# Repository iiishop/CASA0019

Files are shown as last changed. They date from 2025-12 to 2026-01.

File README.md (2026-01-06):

# Study Space Availability and Comfort Monitoring  
**CASA0019 – Sensor Data Visualisation**  
UCL MSc Connected Environments

---

## 1. Introduction & Rationalization

Bookable study spaces play a key role in shaping how students focus, interact, and collaborate. Their availability and atmosphere directly affect both individual productivity and group work.

At UCL, a web-based reservation system allows students to check availability in advance. While effective for scheduling, it represents space mainly through box-style time slots and simplified visuals, offering little insight into experiential qualities such as comfort or suitability for different modes of work. As a result, students often still need to visit spaces in person to assess their appropriateness, and operationally it remains difficult to perceive how spaces respond to changing occupancy and conditions over time.

Prior research shows that students’ study-space choices are shaped by a combination of environmental comfort and functional needs, including noise, privacy, and facilities (Beckers, van der Voordt, & Dewulf, 2016). Indoor environmental conditions have also been shown to significantly influence comfort, satisfaction, and performance, as demonstrated through integrated post-occupancy evaluation approaches combining monitored data with subjective and objective measures (Andargie & Azar, 2019).

This project does not replace the existing system, but reinterprets its data through visualisation. By combining physical data visualisation with a digital twin, it explores how availability and room dynamics can be perceived passively rather than actively queried. Through physical form and visual behaviour, the system frames visualisation as sense-making—supporting everyday student decisions while also providing facilities teams with higher-level insight into learning space performance over time.

<p align="center">
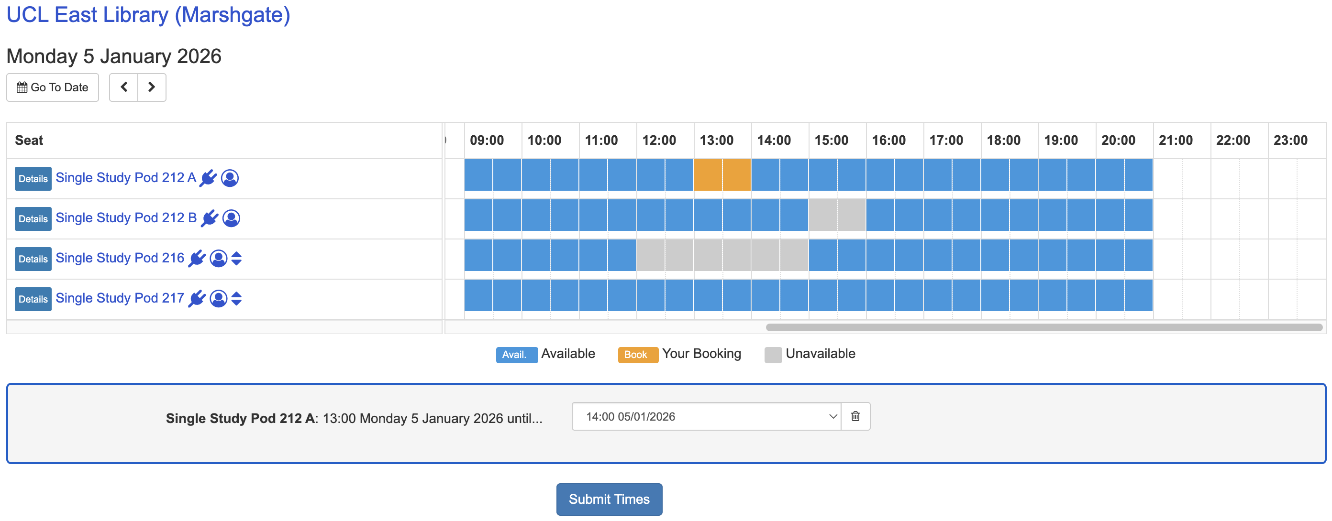
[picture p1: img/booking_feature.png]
Figure 1. Existing Bookable Study Space System
  
</p>

<p align="center"><em>Figure 1. Existing Bookable Study Space System</em></p>

---

## 2. From Data to Visual Language

The project translates key spatial conditions into a visual language that can be perceived intuitively. The system combines two types of data: availability information derived from the UCL Library Reservation booking API, and a set of simulated environmental and behavioural indicators designed to explore how the atmosphere of learning spaces might be communicated visually rather than numerically.

Availability is taken from the booking API and converted into a 30-minute free/booked timeline for each study space across the day (09:00–21:00), updated at regular intervals. This representation supports quick comparison of when a space is likely to be usable, without requiring users to read or interpret detailed schedules or time-slot tables.

To represent comfort and room dynamics, the project focuses on four indicators: occupancy percentage, noise, lighting, and temperature. In the current prototype, these values are synthetically generated within plausible ranges and treated as relative perceptual signals rather than precise measurements. The logic used to generate and update these indicators is implemented in a Python-based simulation module, which is publicly available as part of the project repository (see study_space_simulator.py).

<table align="center">
  <tr>
    <td align="center">
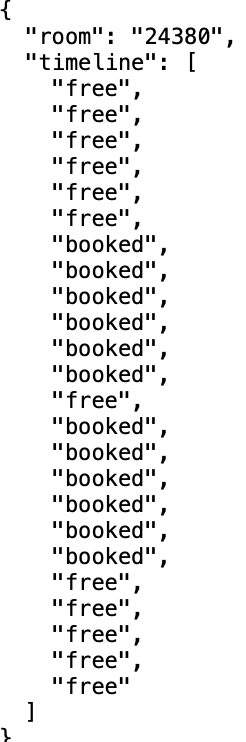
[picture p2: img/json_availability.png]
Figure 2. Sample JSON Output of Availability Data
      
    </td>
    <td align="center">
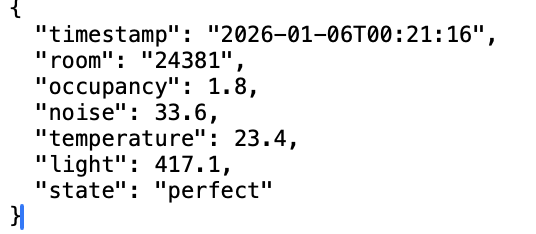
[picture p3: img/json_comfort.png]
Figure 3. Sample JSON Output of Comfort Data
      
    </td>
  </tr>
  <tr>
    <td align="center">
      <em>Figure 2. Sample JSON Output of Availability Data</em>
    </td>
    <td align="center">
      <em>Figure 3. Sample JSON Output of Comfort Data</em>
    </td>
  </tr>
</table>

---

## 3. Physical Data Visualization Device

The physical data visualisation device is conceived as a passive, ambient interface that communicates the state of study spaces at a glance. Rather than functioning as an interactive dashboard, the device supports quick, intuitive interpretation through form, colour, and movement, aligning with everyday study decisions that require rapid assessment rather than detailed analysis.

<p align="center">
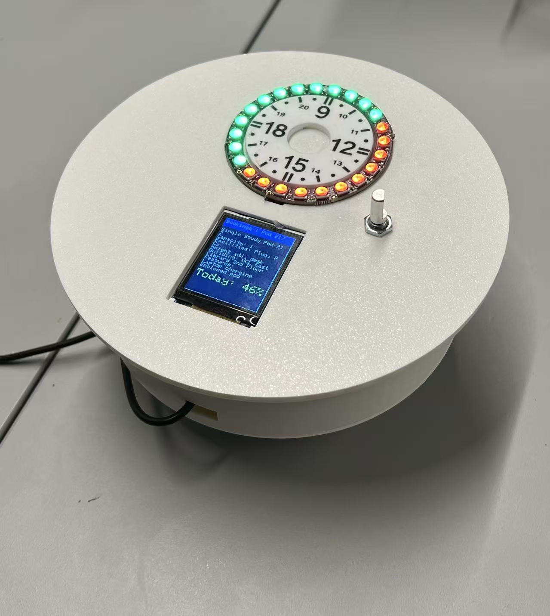
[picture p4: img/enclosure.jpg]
Figure 4. Final Physical Device Enclosure
  
</p>

<p align="center"><em>Figure 4. Final Physical Device Enclosure</em></p>

The device adopts a tabletop form factor with a circular geometry, inspired by the metaphor of a round conference table associated with collaborative learning. The enclosure was designed in Fusion 360 and fabricated through 3D printing, aligning the physical form with the system’s data logic and interaction model. One study space is presented at a time, with navigation handled via a rotary encoder for switching spaces and modes, supporting calm, sequential exploration.

A NeoPixel LED ring serves as the primary medium for temporal and quantitative representation. In Bookings mode, the ring maps the day from 09:00 to 21:00 using 24 LEDs to represent 30-minute intervals, with green indicating availability and red indicating bookings. A circular acrylic overlay, engraved to resemble a watch face, provides a familiar temporal reference for the abstract LED timeline.

In Condition mode, the ring transitions to an animated display of room dynamics, cycling through occupancy, noise, temperature, and lighting. Colour identifies the active attribute, while the number of illuminated LEDs encodes relative magnitude. Progressive filling and rotation communicate intensity and change over time through visual behaviour.

The TFT screen complements the LED ring by providing contextual information. In Bookings mode, it displays room details and overall booking levels, while in Condition mode it presents expressive icons rather than numerical values to reinforce perceptual understanding and reduce cognitive load.

Overall, the device is designed to be readable without instruction. By embedding data within physical form and visual behaviour, it translates abstract spatial information into an intuitive, ambient presence that supports everyday decision-making in learning environments.

<p align="center">
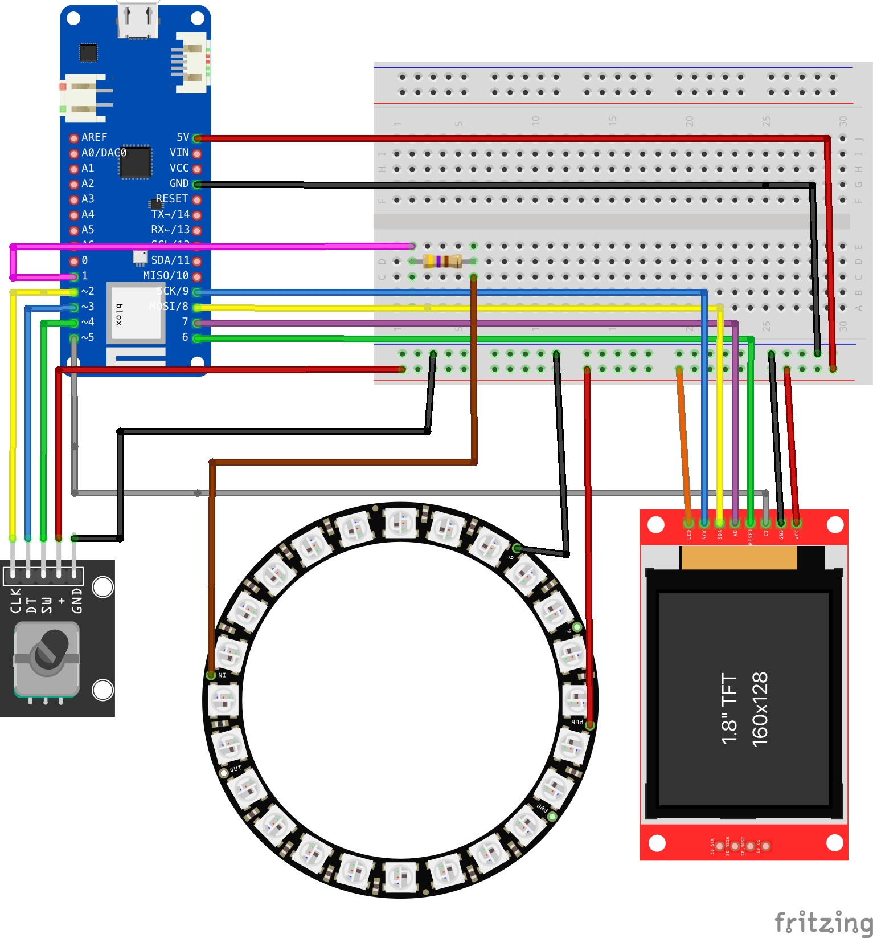
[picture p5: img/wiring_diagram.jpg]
Figure 5. Wiring Diagram
  
</p>

<p align="center"><em>Figure 5. Wiring Diagram</em></p>

---

## 4. Digital Visualization and Digital Twin

The digital twin extends the physical data visualisation device into a complementary digital medium that supports different forms of interpretation. While the physical device is designed for peripheral, glance-based awareness in real space, the digital twin enables closer inspection and comparison without altering the underlying data or system logic.

<p align="center">
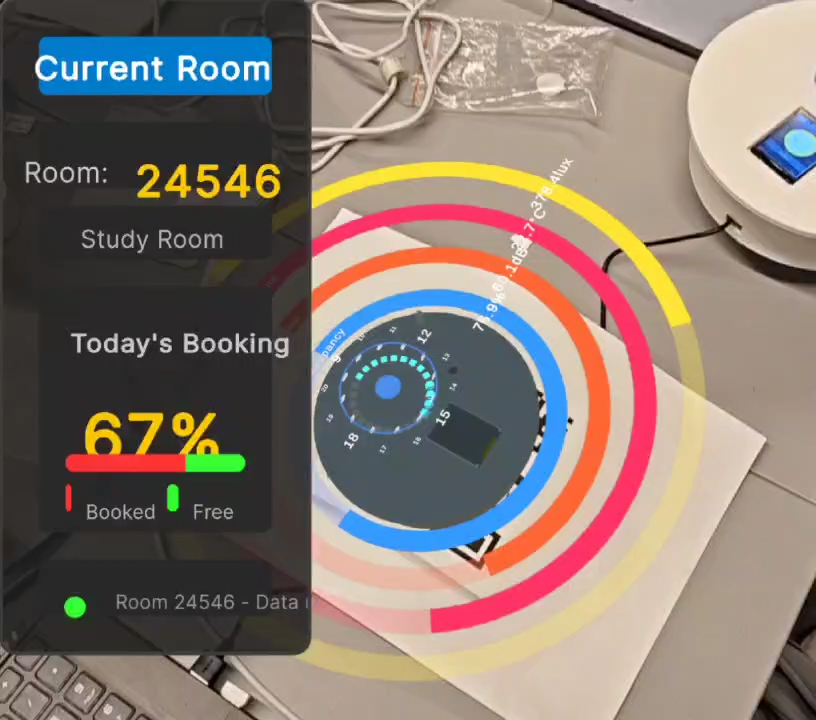
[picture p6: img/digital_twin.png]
Figure 6. Final Digital Twin
  
</p>

<p align="center"><em>Figure 6. Final Digital Twin</em></p>

Both the physical device and the digital twin subscribe to the same MQTT topics and operate on identical data streams, ensuring consistency across media. Colour mappings, modes, and temporal behaviours are preserved, with availability represented through the same red–green logic and environmental conditions expressed using four shared attributes: occupancy, noise, temperature, and lighting. The digital twin therefore functions as a direct extension of the physical visual language.

The primary enrichment offered by the digital twin lies in its spatial and temporal presentation. Unlike the physical NeoPixel ring, which cycles through attributes sequentially to maintain visual simplicity, the digital twin presents all four indicators simultaneously using concentric rings. This allows conditions to be read in parallel and compared directly. Quantitative values and units are also displayed to support verification when greater precision is required.

The digital twin additionally introduces persistence. Environmental states remain visible until updated, enabling pausing, comparison, and reflection—activities that are intentionally unsupported by the physical device, where meaning emerges through motion and change. Users typically transition to the digital twin when moving from ambient awareness to focused inquiry, for example to understand why a space appears busy, noisy, or uncomfortable.

Rather than functioning as a conventional dashboard, the digital twin preserves the same visual grammar as the physical device while extending legibility, persistence, and simultaneity. This allows the same data to be interpreted differently across media without changing its underlying meaning.

Our approach aligns with digital-twin implementations in educational buildings that integrate real-time IoT sensing with a spatial model to visualise indoor environmental conditions and support operational decisions (Opoku et al., 2024).

---

## 5. Physical-Digital Integration

A core design principle of this project is the maintenance of a shared visual language across physical and digital representations. Rather than functioning as separate interfaces, the physical device and digital twin operate as parallel expressions of the same underlying data mappings, ensuring that meaning is preserved as users move between media.

Both systems apply identical visual rules: colour distinguishes attributes such as occupancy, noise, temperature, and lighting, while quantity and radial extent represent relative intensity. Temporal behaviours, including gradual filling and rhythmic transitions, are used consistently to communicate change over time. By transforming data once conceptually and applying it across media, the system supports continuity of interpretation while allowing each interface to emphasise its respective strengths—ambient awareness in the physical device and persistence and comparison in the digital twin.

---

## 6. Development Process & Visual Iteration

The project evolved through iterative testing of how much information could be communicated visually without overwhelming the user. An early proposal to display all five study spaces simultaneously using multiple NeoPixel rings was abandoned after prototyping revealed both physical complexity (wiring, power management) and cognitive overload. Instead, the interaction was refocused on a single space at a time, navigated via a rotary encoder, prioritising clarity and interpretability.

A key visual iteration concerned how room conditions were summarised. Rather than introducing additional numerical readouts or text, the system adopts expressive emoticons to represent overall room state. This approach was chosen to encourage emotional and intuitive interpretation—allowing users to sense whether a space “feels” calm, busy, or uncomfortable at a glance—without requiring analytical reading.

Another challenge involved representing multiple comfort attributes with different units and scales. Early ideas to place all scales directly on the device were rejected, as this quickly crowded the surface and conflicted with the ambient nature of the display. Instead, scale definitions and mappings were externalised into an online guideline booklet, maintaining visual simplicity on the device itself. While alternative solutions—such as printing legends directly onto the device—were considered, a fully satisfactory integration was not finalised within the project timeframe.

<p align="center">
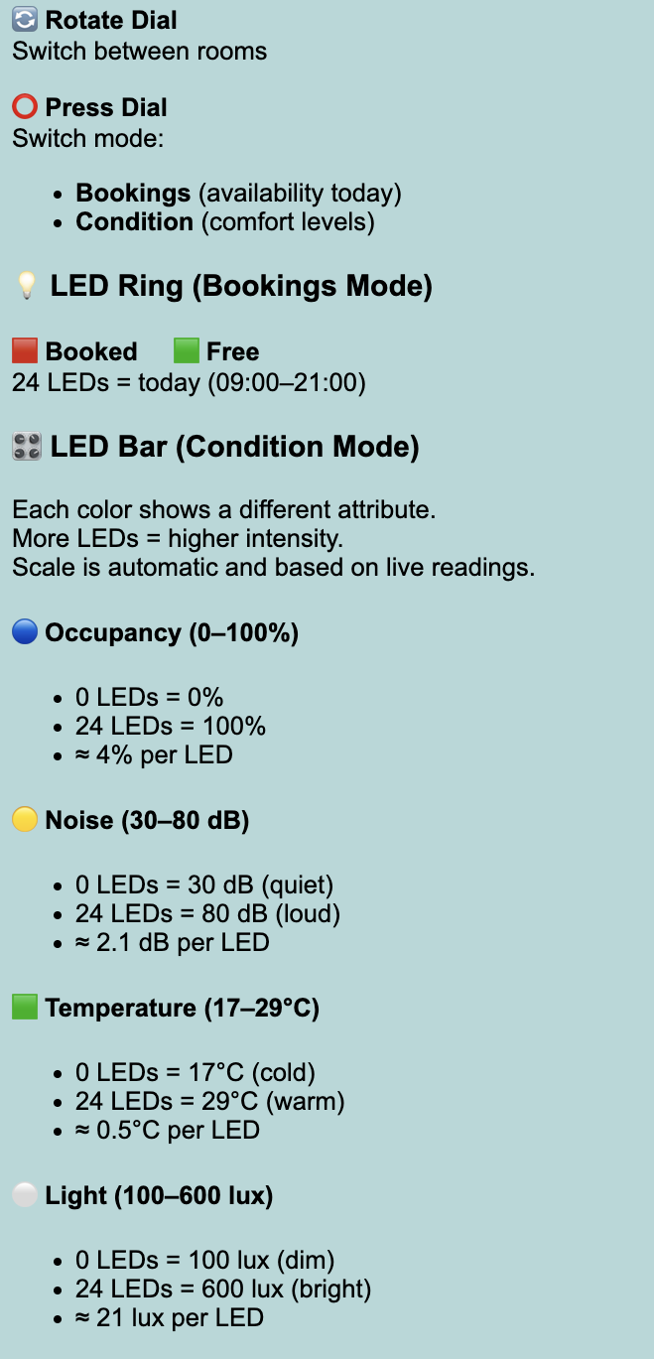
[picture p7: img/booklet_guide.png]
Figure 7. Scale Description on Online Guideline Booklet
  
</p>

<p align="center"><em>Figure 7. Scale Description on Online Guideline Booklet</em></p>

Material choices were also iterated. Although a wooden or laser-cut tabletop form was initially envisioned, time constraints led to a 3D-printed enclosure, refined through technical guidance to improve legibility and tactility. Together, these iterations reflect a balance between expressiveness, legibility, and practical stability.

---

## 7. Evaluation: Readability & Perception

The NeoPixel ring proved highly legible for temporal availability. The circular layout aligns naturally with a time-based mental model, allowing users to distinguish booked and free slots without textual explanation. Colour contrast between booked and free states enabled rapid pattern recognition, particularly when viewed from a distance. The physical rotation offset, mirrored in the digital twin, helped reinforce spatial orientation and reduced ambiguity.

For environmental conditions, readability was evaluated through perceptual differentiation rather than numerical accuracy. Progressive illumination and colour shifts allowed users to compare relative comfort levels without requiring interpretation of exact values. The use of emotive symbols further supported immediate comprehension by translating complex sensor data into affective cues.

The digital twin played a critical evaluative role by revealing limitations not visible in the physical artefact alone. On-screen overlays and zoomed perspectives exposed moments where colour similarity or animation speed reduced clarity, informing subsequent adjustments to thresholds and transitions.

Overall, the system prioritises perceptual coherence over analytical precision. Its success lies in enabling users to quickly judge whether a space is suitable rather than why in numerical terms, supporting lightweight decision-making in everyday contexts.

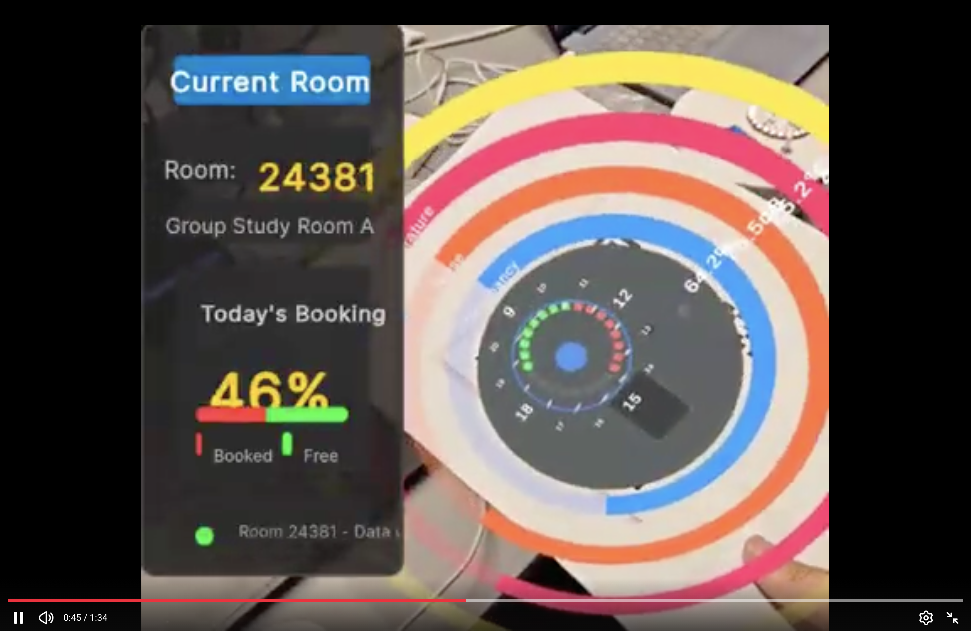
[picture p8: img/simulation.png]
Demo Video (https://www.youtube.com//watch?v=DgZtPRBeWZ0)
🚀 See the project come to life! Watch the demo on Youtube here: 

*Figure 8. Video demonstrating two different modes on the physical device and its digital twin*

---

## 8. Reflection & Future Visual Extensions

This project highlights how quickly visual richness can become cognitive complexity. Although the system was deliberately limited to five study spaces and two primary modes, the combined use of colour, motion, and spatial encoding still requires an initial period of interpretation. For first-time users, the NeoPixel rings communicate presence and intensity effectively, but the absence of an embedded legend means that understanding relies on inference rather than immediate clarity. While this aligns with the goal of ambient, non-intrusive visualisation, it also reveals a tension between expressiveness and accessibility.

A key future extension is to move beyond observing availability toward enabling booking directly through the system. This would transform the device from a passive visualisation into an actionable interface while preserving its ambient character.

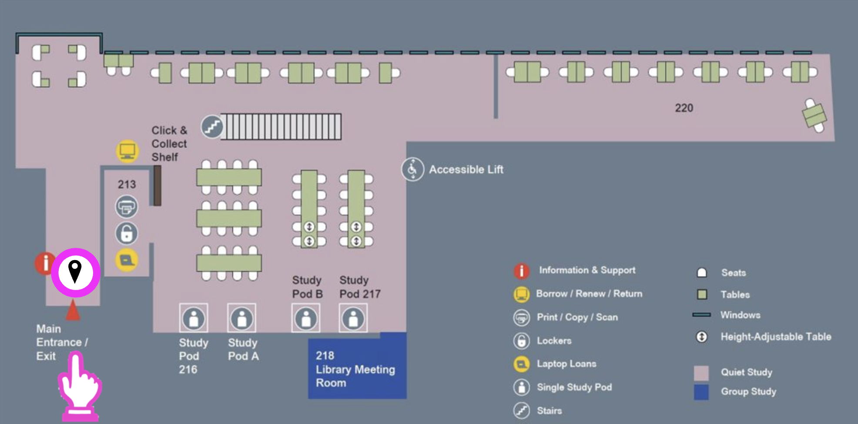
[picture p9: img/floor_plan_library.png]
Figure 9. Bookable Study Space in UCL East Library (Study Pod & Meeting Room)

*Figure 9. Bookable Study Space in UCL East Library (Study Pod & Meeting Room)*

The following outlines the proposed step-by-step workflow:

1. **Extending Bookings mode to support selection**<br>
   The rotary encoder is used to step through individual 30-minute time slots around the LED ring, with a temporary visual highlight indicating the current selection.

2. **Expressing booking intent through MQTT**<br>
   A long press publishes a booking intent message containing the selected room ID and time range.

3. **Validation through a service layer**<br>
   A backend service receives the booking intent and verifies availability against the live booking API.

4. **Completing booking through official channels**<br>
   Users are redirected to the existing booking system with the selected room and time pre-filled.

5. **Immediate visual feedback**<br>
   Confirmation or rejection is reflected on both the physical device and the digital twin through brief visual animations.

Alongside functional expansion, future iterations would also focus on reducing perceptual load: softer LED output, more gradual animations, and clearer onboarding through subtle, built-in guidance rather than external documentation. These changes would strengthen the device’s role as a calm, intelligible interface embedded within everyday study environments.

---

## 9. Individual Contributions

This project was developed collaboratively. Gilang Pamungkas led the system concept, interaction design, and physical device software; Yuqian Lin developed the digital twin and AR visualisation; Chaoshuo Han designed and modelled the physical enclosure; Cheng Zhong coordinated integration and report structure. The report was jointly written by all team members.

---

Reference

Andargie, M.S. and Azar, E. (2019) ‘An applied framework to evaluate the impact of indoor office environmental factors on occupants’ comfort and working conditions’, Sustainable Cities and Society, 46, 101447. https://doi.org/10.1016/j.scs.2019.101447

Beckers, R., van der Voordt, T. and Dewulf, G. (2016) ‘Learning space preferences of higher education students’, Building and Environment, 104, pp. 243–252. https://doi.org/10.1016/j.buildenv.2016.05.013

Opoku, D.-G.J., Perera, S., Osei-Kyei, R., Rashidi, M., Bamdad, K. and Famakinwa, T. (2024) ‘Digital twin for indoor condition monitoring in living labs: University library case study’, Automation in Construction, 157, 105188. https://doi.org/10.1016/j.autcon.2023.105188

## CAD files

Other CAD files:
CASA0019-1.f3z

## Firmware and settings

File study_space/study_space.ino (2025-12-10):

/****************************************************
 * UCL Study Space Visualiser
 * Rotary Encoder Version
 * - Rotate encoder to change room
 * - Push encoder to change mode (Bookings / Condition)
 *
 * Bookings mode:
 *  - NeoPixel: 24 slots (09:00–21:00, 30 mins each)
 *              red = booked, green = free
 *  - TFT: room details (name, capacity, facilities)
 *
 * Condition mode:
 *  - TFT: expressive emoji based on "state"
 *  - NeoPixel: animated bar for 4 attributes
 *              occupancy / noise / temperature / light
 ****************************************************/

#include <SPI.h>
#include <WiFiNINA.h>
#include <PubSubClient.h>
#include <ArduinoJson.h>
#include <Adafruit_GFX.h>
#include <Adafruit_ST7735.h>
#include <Adafruit_NeoPixel.h>
#include "arduino_secrets.h"

// --------------------------------------------------
// TFT ST7735
// --------------------------------------------------
#define TFT_CS 5
#define TFT_DC 7
#define TFT_RST 6

Adafruit_ST7735 tft = Adafruit_ST7735(TFT_CS, TFT_DC, TFT_RST);

// Screen margins to avoid dead pixels
const int LEFT_MARGIN = 5;                                 // Left margin to avoid vertical dead line
const int RIGHT_MARGIN = 5;                                // Right margin for symmetry
const int USABLE_WIDTH = 128 - LEFT_MARGIN - RIGHT_MARGIN; // 118 pixels

const int CX = 64;
const int CY = 70;

// --------------------------------------------------
// NEOPIXEL RING (24x SK6812 RGBW)
// --------------------------------------------------
#define NEOPIXEL_PIN 1
#define LED_COUNT 24

// Ring is GRBW
Adafruit_NeoPixel strip(LED_COUNT, NEOPIXEL_PIN, NEO_GRBW + NEO_KHZ800);

// --------------------------------------------------
// ROTARY ENCODER PINS
// --------------------------------------------------
#define ENC_CLK 2
#define ENC_DT 3
#define ENC_SW 4

int lastClk = HIGH;
bool lastButton = HIGH;
unsigned long lastButtonTime = 0;
const unsigned long BUTTON_DEBOUNCE = 180;

unsigned long lastModePublishTime = 0; // Track when we published mode (for future use if needed)

// --------------------------------------------------
// WIFI + MQTT
// --------------------------------------------------

// WiFi credentials + MQTT_* (including MQTT_BASE) come from arduino_secrets.h

WiFiClient wifiClient;
PubSubClient mqttClient(wifiClient);

// --------------------------------------------------
// ROOMS & METADATA
// --------------------------------------------------
const uint8_t ROOM_COUNT = 5;

const char *ROOM_IDS[ROOM_COUNT] = {
    "24380",
    "24381",
    "24382",
    "24546",
    "24547"};

const char *ROOM_NAMES[ROOM_COUNT] = {
    "Pod 216",
    "Pod 217",
    "Group 218",
    "Pod 212A",
    "Pod 212B"};

const char *ROOM_DETAILS[ROOM_COUNT] = {
    "Single Study Pod 216\n"
    "Capacity: 1\n"
    "Facilities: Plug, PC,\nheight adj. desk\n"
    "Building: UCL East\nLibrary 2nd Floor\n"
    "Features:\nLaptop charging\nEnclosed pod",

    "Single Study Pod 217\n"
    "Capacity: 1\n"
    "Facilities: Plug, PC,\nheight adj. desk\n"
    "Building: UCL East\nLibrary 2nd Floor\n"
    "Features:\nLaptop charging\nEnclosed pod",

    "Group Study Room 218\n"
    "Capacity: 6\n"
    "Facilities: Plug,\nmonitor for laptop\n"
    "Building: UCL East\nLibrary 2nd Floor\n"
    "Features:\nLaptop charging\nEnclosed room",

    "Single Study Pod 212A\n"
    "Capacity: 1\n"
    "Facilities: Plug\n"
    "Building: UCL East\nLibrary 2nd Floor\n"
    "Features:\nLaptop charging\nEnclosed pod",

    "Single Study Pod 212B\n"
    "Capacity: 1\n"
    "Facilities: Plug\n"
    "Building: UCL East\nLibrary 2nd Floor\n"
    "Features:\nLaptop charging\nEnclosed pod"};

// --------------------------------------------------
// ROOM DATA STRUCTURE
// --------------------------------------------------
struct RoomData
{
  bool hasStatus = false;
  float occupancy = 0;
  float noise = 0;
  float temperature = 0;
  float light = 0;
  String state = "neutral";

  bool hasTimeline = false;
  int timelineLen = 0;
  bool slotBooked[LED_COUNT];
};

RoomData rooms[ROOM_COUNT];

// --------------------------------------------------
// UI STATE
// --------------------------------------------------
bool timelineMode = true; // true = Bookings
int selectedRoom = 0;

unsigned long lastAttrChange = 0;
unsigned long lastAnimStep = 0;

uint8_t currentAttr = 0; // 0=occ,1=noise,2=temp,3=light
int currentLEDCount = 0;
int targetLEDCount = 0;

// --------------------------------------------------
// TFT COLORS
// --------------------------------------------------
uint16_t FACE1, FACE2, FACE3;
uint16_t EYE, MOUTH, CHEEK;
uint16_t WARM1, WARM2;
uint16_t COLD1;
uint16_t BG;

// --------------------------------------------------
// HELPER: room ID → index
// --------------------------------------------------
int roomIndexFromId(const String &id)
{
  for (int i = 0; i < ROOM_COUNT; i++)
  {
    if (id == ROOM_IDS[i])
      return i;
  }
  return -1;
}

// --------------------------------------------------
// WIFI CONNECT  (multi-SSID: CE-Hub-Student, then Gilang)
// --------------------------------------------------
void connectWiFi()
{
  Serial.println("Connecting to WiFi...");

  for (int i = 0; i < numNetworks; i++)
  {
    Serial.print("Trying SSID: ");
    Serial.println(ssids[i]);

    WiFi.begin(ssids[i], passwords[i]);
    unsigned long startAttempt = millis();

    // Try for ~8 seconds per network
    while (WiFi.status() != WL_CONNECTED &&
           millis() - startAttempt < 8000)
    {
      Serial.print(".");
      delay(400);
    }

    if (WiFi.status() == WL_CONNECTED)
    {
      Serial.println("\nConnected!");
      Serial.print("SSID: ");
      Serial.println(ssids[i]);
      Serial.print("IP Address: ");
      Serial.println(WiFi.localIP());
      return; // success
    }

    Serial.println("\nFailed. Trying next network...");
  }

  // If all networks fail, retry forever
  Serial.println("All WiFi attempts failed. Retrying...");
  delay(2000);
  connectWiFi();
}

// --------------------------------------------------
// NEOPIXEL HELPERS
// --------------------------------------------------
// LED position offset correction:
// Physical ring starts at 11 o'clock (LED 0)
// Logical timeline starts at 9 o'clock
// Need to shift back 4 positions: (index + 20) % 24
int mapLEDIndex(int logicalIndex)
{
  // Shift by 20 (which is 24-4) to move 9 o'clock position to LED 0
  return (logicalIndex + 20) % LED_COUNT;
}

void clearStrip()
{
  for (int i = 0; i < LED_COUNT; i++)
  {
    strip.setPixelColor(i, 0);
  }
  strip.show();
}

// --------------------------------------------------
// TIMELINE RENDERING (Bookings mode)
// --------------------------------------------------
void renderTimeline(int idx)
{
  clearStrip();

  RoomData &rd = rooms[idx];
  if (!rd.hasTimeline)
  {
    Serial.println("renderTimeline: no timeline for this room yet");
    return;
  }

  int N = rd.timelineLen;
  if (N > LED_COUNT)
    N = LED_COUNT;

  Serial.print("renderTimeline: room ");
  Serial.print(ROOM_IDS[idx]);
  Serial.print(" slots=");
  Serial.println(N);

  for (int i = 0; i < N; i++)
  {
    uint32_t c = rd.slotBooked[i]
                     ? strip.Color(255, 0, 0, 0)  // red = booked
                     : strip.Color(0, 255, 0, 0); // green = free

    // Map logical time slot to physical LED position
    int physicalLED = mapLEDIndex(i);
    strip.setPixelColor(physicalLED, c);
    strip.show();
    delay(60);
  }
}

// --------------------------------------------------
// STATUS MODE ANIMATION ENGINE
// --------------------------------------------------
uint32_t attrColor(int attr)
{
  switch (attr)
  {
  case 0:
    // Occupancy → deep blue
    return strip.Color(0, 20, 255, 0);

  case 1:
    // Noise → warm yellow
    return strip.Color(255, 255, 0, 0);

  case 2:
    // Temperature → warm-ish
    return strip.Color(0, 255, 0, 20);

  case 3:
    // Light → soft white
    return strip.Color(0, 0, 0, 80);
  }
  return strip.Color(0, 0, 0, 0);
}

void computeAttrTarget(const RoomData &rd, int attr)
{
  switch (attr)
  {
  case 0:
    targetLEDCount = rd.occupancy / 4.2;
    break; // 0–100 → 0–24
  case 1:
    targetLEDCount = (rd.noise - 30) / 2.1;
    break; // 30–80
  case 2:
    targetLEDCount = (rd.temperature - 17) * 2;
    break; // 17–29
  case 3:
    targetLEDCount = (rd.light - 100) / 21.0;
    break; // 100–600
  }
  targetLEDCount = constrain(targetLEDCount, 0, LED_COUNT);
  currentLEDCount = 0;
}

void updateStatusAnimation()
{
  RoomData &rd = rooms[selectedRoom];
  if (!rd.hasStatus)
    return;

  unsigned long now = millis();

  // Rotate attribute every 5s
  if (now - lastAttrChange > 5000)
  {
    lastAttrChange = now;
    currentAttr = (currentAttr + 1) % 4;
    computeAttrTarget(rd, currentAttr);
    clearStrip();
  }

  // Progressive fill
  if (now - lastAnimStep > 120)
  {
    lastAnimStep = now;
    if (currentLEDCount < targetLEDCount)
    {
      // Map logical position to physical LED
      int physicalLED = mapLEDIndex(currentLEDCount);
      strip.setPixelColor(physicalLED, attrColor(currentAttr));
      strip.show();
      currentLEDCount++;
    }
  }
}

// --------------------------------------------------
// COLOR SETUP
// --------------------------------------------------
void setupColors()
{
  BG = ST7735_BLACK;

  FACE1 = tft.color565(255, 170, 0);
  FACE2 = tft.color565(255, 200, 0);
  FACE3 = tft.color565(255, 230, 100);

  EYE = tft.color565(50, 30, 10);
  MOUTH = tft.color565(200, 0, 0);
  CHEEK = tft.color565(255, 120, 120);

  WARM1 = tft.color565(255, 80, 20);
  WARM2 = tft.color565(255, 140, 60);

  COLD1 = tft.color565(150, 200, 255);
}

// -----------------------------------------------------------
// TFT HEADER
// -----------------------------------------------------------
void drawHeader(int roomIndex)
{
  tft.fillRect(0, 0, 128, 20, ST7735_BLUE);

  tft.setTextSize(1);
  tft.setTextColor(ST7735_WHITE);
  tft.setCursor(LEFT_MARGIN, 5);

  if (timelineMode)
  {
    tft.print("Bookings | ");
  }
  else
  {
    tft.print("Condition | ");
  }

  tft.print(ROOM_NAMES[roomIndex]);
}

// -----------------------------------------------------------
// CAPTION (Condition mode only)
// -----------------------------------------------------------
void caption(const char *s)
{
  uint16_t shade = tft.color565(40, 40, 40);
  tft.fillRect(0, 120, 128, 20, shade);

  tft.setTextColor(ST7735_WHITE);
  tft.setTextSize(1);

  int16_t x1, y1;
  uint16_t w, h;
  tft.getTextBounds((char *)s, 0, 0, &x1, &y1, &w, &h);

  // Center within usable width, considering margins
  int x = LEFT_MARGIN + (USABLE_WIDTH - (int)w) / 2;
  if (x < LEFT_MARGIN)
    x = LEFT_MARGIN; // Ensure minimum margin

  tft.setCursor(x, 128);
  tft.print(s);
}

// -----------------------------------------------------------
// TEXT PRINTING WITH MARGIN HANDLING
// -----------------------------------------------------------
void printWithMargin(const char *text, int startX, int startY)
{
  // This function prints text with proper margin handling
  // It manually handles line breaks to respect the right margin

  int cursorX = startX;
  int cursorY = startY;
  int charWidth = 6;  // Character width for text size 1
  int lineHeight = 8; // Line height for text size 1
  int maxWidth = USABLE_WIDTH;

  String str = String(text);
  int len = str.length();

  for (int i = 0; i < len; i++)
  {
    char c = str.charAt(i);

    // Handle newline
    if (c == '\n')
    {
      cursorX = startX;
      cursorY += lineHeight;
      continue;
    }

    // Check if we need to wrap
    if (cursorX + charWidth > startX + maxWidth)
    {
      cursorX = startX;
      cursorY += lineHeight;
    }

    // Don't print beyond screen bottom
    if (cursorY > 115)
      break;

    tft.setCursor(cursorX, cursorY);
    tft.print(c);
    cursorX += charWidth;
  }
}

// -----------------------------------------------------------
// FACE DRAWING HELPERS
// -----------------------------------------------------------
void clearIcon()
{
  // Clear main emoji area (20–120)
  tft.fillRect(0, 20, 128, 100, BG);
}

void drawFaceBase()
{
  clearIcon();
  tft.fillCircle(CX, CY, 42, FACE1);
  tft.fillCircle(CX, CY, 38, FACE2);
  tft.fillCircle(CX, CY, 32, FACE3);
}

void eyeHappySoft(int x, int y)
{
  tft.drawLine(x - 6, y, x, y - 4, EYE);
  tft.drawLine(x, y - 4, x + 6, y, EYE);
}

void eyeBusyLeft(int x, int y)
{
  tft.drawLine(x - 6, y - 2, x + 2, y + 1, EYE);
}

void eyeBusyRight(int x, int y)
{
  tft.drawLine(x - 2, y + 1, x + 6, y - 2, EYE);
}

void eyeSleepy(int x, int y)
{
  tft.drawLine(x - 6, y, x + 6, y + 2, EYE);
}

void eyebrowAngry(int x, int y)
{
  tft.drawLine(x - 8, y - 8, x + 2, y - 12, EYE);
  tft.drawLine(x + 2, y - 12, x + 12, y - 8, EYE);
}

void mouthZigZag()
{
  tft.drawLine(CX - 14, CY + 18, CX - 7, CY + 14, MOUTH);
  tft.drawLine(CX - 7, CY + 14, CX, CY + 18, MOUTH);
  tft.drawLine(CX, CY + 18, CX + 7, CY + 14, MOUTH);
  tft.drawLine(CX + 7, CY + 14, CX + 14, CY + 18, MOUTH);
}

void mouthChatter()
{
  tft.fillRect(CX - 14, CY + 12, 28, 8, ST7735_WHITE);
  for (int i = 0; i < 6; i++)
  {
    tft.drawLine(CX - 14 + i * 5, CY + 12,
                 CX - 14 + i * 5, CY + 20,
                 EYE);
  }
}

// -----------------------------------------------------------
// EMOTICONS WITH CAPTION (Condition mode)
// -----------------------------------------------------------
void iconPerfect()
{
  drawFaceBase();
  tft.fillRoundRect(CX - 25, CY - 12, 16, 12, 4, EYE);
  tft.fillRoundRect(CX + 9, CY - 12, 16, 12, 4, EYE);
  tft.fillCircle(CX, CY + 18, 16, MOUTH);
  tft.fillCircle(CX, CY + 10, 16, FACE3);
  tft.fillCircle(CX - 22, CY + 10, 6, CHEEK);
  tft.fillCircle(CX + 22, CY + 10, 6, CHEEK);
  caption("Perfect");
}

void iconGood()
{
  drawFaceBase();
  eyeHappySoft(CX - 20, CY - 8);
  eyeHappySoft(CX + 20, CY - 8);
  tft.drawLine(CX - 16, CY + 16, CX + 16, CY + 14, MOUTH);
  tft.drawLine(CX - 16, CY + 17, CX + 16, CY + 15, MOUTH);
  tft.fillCircle(CX - 22, CY + 12, 6, CHEEK);
  tft.fillCircle(CX + 22, CY + 12, 6, CHEEK);
  caption("Good");
}

void iconCalm()
{
  drawFaceBase();
  tft.drawLine(CX - 26, CY - 4, CX - 14, CY - 6, EYE);
  tft.drawLine(CX + 14, CY - 6, CX + 26, CY - 4, EYE);
  tft.drawLine(CX - 10, CY + 17, CX, CY + 19, MOUTH);
  tft.drawLine(CX, CY + 19, CX + 10, CY + 17, MOUTH);
  tft.fillCircle(CX - 22, CY + 10, 5, CHEEK);
  tft.fillCircle(CX + 22, CY + 10, 5, CHEEK);
  caption("Calm");
}

void iconNeutral()
{
  drawFaceBase();
  tft.fillRoundRect(CX - 26, CY - 12, 16, 10, 3, EYE);
  tft.fillRoundRect(CX + 10, CY - 12, 16, 10, 3, EYE);
  tft.fillRect(CX - 14, CY + 16, 28, 3, EYE);
  caption("Neutral");
}

void iconBusy()
{
  drawFaceBase();
  eyeBusyLeft(CX - 20, CY - 10);
  eyeBusyRight(CX + 20, CY - 10);
  tft.fillCircle(CX, CY + 18, 6, MOUTH);
  tft.fillCircle(CX + 28, CY + 15, 6, ST7735_WHITE);
  tft.fillCircle(CX + 34, CY + 15, 4, ST7735_WHITE);
  tft.fillCircle(CX + 38, CY + 15, 3, ST7735_WHITE);
  caption("Busy");
}

void iconNoisy()
{
  drawFaceBase();
  eyebrowAngry(CX - 20, CY - 10);
  eyebrowAngry(CX + 20, CY - 10);
  tft.drawLine(CX - 26, CY - 4, CX - 14, CY + 2, EYE);
  tft.drawLine(CX - 26, CY + 2, CX - 14, CY - 4, EYE);
  tft.drawLine(CX + 14, CY - 4, CX + 26, CY + 2, EYE);
  tft.drawLine(CX + 14, CY + 2, CX + 26, CY - 4, EYE);
  mouthZigZag();
  tft.drawLine(10, CY - 5, 20, CY - 10, EYE);
  tft.drawLine(108, CY - 5, 118, CY - 10, EYE);
  caption("Noisy");
}

void iconWarm()
{
  drawFaceBase();
  tft.drawLine(CX - 26, CY - 4, CX - 14, CY - 2, EYE);
  tft.drawLine(CX + 14, CY - 2, CX + 26, CY - 4, EYE);
  tft.drawLine(CX - 30, CY - 25, CX - 20, CY - 20, WARM1);
  tft.drawLine(CX - 20, CY - 20, CX - 30, CY - 15, WARM1);
  tft.drawLine(CX + 30, CY - 25, CX + 20, CY - 20, WARM1);
  tft.drawLine(CX + 20, CY - 20, CX + 30, CY - 15, WARM1);
  tft.fillCircle(CX - 26, CY + 4, 4, WARM2);
  tft.fillCircle(CX + 26, CY + 4, 4, WARM2);
  tft.fillCircle(CX, CY + 20, 10, MOUTH);
  tft.fillCircle(CX, CY + 18, 10, FACE3);
  caption("Warm");
}

void iconCold()
{
  drawFaceBase();
  tft.drawLine(CX - 28, CY - 16, CX - 12, CY - 22, EYE);
  tft.drawLine(CX + 12, CY - 22, CX + 28, CY - 16, EYE);
  tft.drawLine(CX - 22, CY - 6, CX - 14, CY - 4, EYE);
  tft.drawLine(CX + 14, CY - 4, CX + 22, CY - 6, EYE);
  mouthChatter();
  tft.fillCircle(CX - 30, CY + 4, 3, COLD1);
  tft.fillCircle(CX + 30, CY + 4, 3, COLD1);
  caption("Cold");
}

void iconDim()
{
  drawFaceBase();
  eyeSleepy(CX - 20, CY - 6);
  eyeSleepy(CX + 20, CY - 6);
  tft.drawLine(CX - 12, CY + 18, CX + 12, CY + 20, MOUTH);
  tft.setTextColor(ST7735_WHITE);
  tft.setTextSize(1);
  tft.setCursor(CX + 20, CY - 25);
  tft.print("Z");
  caption("Dim");
}

void iconOverloaded()
{
  drawFaceBase();
  tft.drawCircle(CX - 20, CY - 10, 8, EYE);
  tft.drawCircle(CX + 20, CY - 10, 8, EYE);
  tft.drawCircle(CX - 20, CY - 10, 4, EYE);
  tft.drawCircle(CX + 20, CY - 10, 4, EYE);
  mouthZigZag();
  tft.drawLine(10, CY - 15, 25, CY - 25, MOUTH);
  tft.drawLine(118, CY - 15, 103, CY - 25, MOUTH);
  caption("Overloaded");
}

// -----------------------------------------------------------
// STATE → ICON SELECTOR
// -----------------------------------------------------------
void drawStateIcon(const String &state)
{
  if (state == "perfect")
    iconPerfect();
  else if (state == "good")
    iconGood();
  else if (state == "calm")
    iconCalm();
  else if (state == "busy")
    iconBusy();
  else if (state == "noisy")
    iconNoisy();
  else if (state == "warm")
    iconWarm();
  else if (state == "cold")
    iconCold();
  else if (state == "dim")
    iconDim();
  else if (state == "overloaded")
    iconOverloaded();
  else
    iconNeutral();
}
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
void loop()
{
  // MQTT keep-alive
  if (!mqttClient.connected())
  {
    connectMQTT();
  }
  mqttClient.loop();

  // --- ROTARY ENCODER ROTATION ---
  int currentClk = digitalRead(ENC_CLK);
  if (currentClk != lastClk)
  {
    if (currentClk == LOW)
    {
      // Direction
      bool clockwise = (digitalRead(ENC_DT) != currentClk);

      if (clockwise)
      {
        selectedRoom = (selectedRoom + 1) % ROOM_COUNT;

        // Publish MQTT event for clockwise rotation (retained)
        String payload = "{\"encoder\":\"rotation\",\"direction\":\"cw\"}";
        mqttClient.publish("student/CASA0019/Gilang/encoder", payload.c_str(), true);
        Serial.println("[ENCODER] Published: CW rotation (retained)");

        // Publish current room change
        String roomPayload = "{\"current_room\":\"" + String(ROOM_IDS[selectedRoom]) + "\"}";
        mqttClient.publish("student/CASA0019/Gilang/studyspace/current", roomPayload.c_str());
        Serial.print("[ROOM] Published current room: ");
        Serial.println(ROOM_IDS[selectedRoom]);
      }
      else
      {
        selectedRoom--;
        if (selectedRoom < 0)
          selectedRoom = ROOM_COUNT - 1;

        // Publish MQTT event for counter-clockwise rotation (retained)
        String payload = "{\"encoder\":\"rotation\",\"direction\":\"ccw\"}";
        mqttClient.publish("student/CASA0019/Gilang/encoder", payload.c_str(), true);
        Serial.println("[ENCODER] Published: CCW rotation (retained)");

        // Publish current room change
        String roomPayload = "{\"current_room\":\"" + String(ROOM_IDS[selectedRoom]) + "\"}";
        mqttClient.publish("student/CASA0019/Gilang/studyspace/current", roomPayload.c_str());
        Serial.print("[ROOM] Published current room: ");
        Serial.println(ROOM_IDS[selectedRoom]);
      }

      Serial.print("Room → ");
      Serial.print(ROOM_IDS[selectedRoom]);
      Serial.print(" (");
      Serial.print(ROOM_NAMES[selectedRoom]);
      Serial.println(")");

      // Clear existing data for the new room to force fresh data fetch
      rooms[selectedRoom].hasTimeline = false;
      rooms[selectedRoom].hasStatus = false;

      // Show loading state
      if (timelineMode)
      {
        showRoomDetails(selectedRoom);
        clearStrip();
        Serial.println("[ROOM] Waiting for fresh timeline data from UCL API...");
      }
      else
      {
        drawHeader(selectedRoom);
        iconNeutral();
        clearStrip();
        Serial.println("[ROOM] Waiting for fresh status data from UCL API...");
      }
    }
    lastClk = currentClk;
  }

  // --- ROTARY BUTTON (PUBLISH MQTT ONLY) ---
  bool b = digitalRead(ENC_SW);
  if (b != lastButton && (millis() - lastButtonTime > BUTTON_DEBOUNCE))
  {
    lastButtonTime = millis();
    lastButton = b;
    if (b == LOW)
    {
      Serial.println("[ENCODER] Physical button pressed");

      // Calculate new mode
      bool newTimelineMode = !timelineMode;
      String newMode = newTimelineMode ? "bookings" : "condition";

      // Publish mode change to MQTT (retained)
      // This will trigger mode update on both Arduino (via callback) and Unity
      String modePayload = "{\"mode\":\"" + newMode + "\"}";
      mqttClient.publish("student/CASA0019/Gilang/studyspace/mode", modePayload.c_str(), true);
      lastModePublishTime = millis(); // Record publish time

      Serial.print("[ENCODER] Published mode change (retained): ");
      Serial.println(newMode);
      Serial.println("[ENCODER] Waiting for mode callback to update display...");

      // Optional: Also publish button event for logging/analytics
      String buttonPayload = "{\"encoder\":\"button\",\"pressed\":true}";
      mqttClient.publish("student/CASA0019/Gilang/encoder", buttonPayload.c_str(), false);
    }
  }

  // --- CONDITION MODE ANIMATION ---
  if (!timelineMode)
  {
    updateStatusAnimation();
  }

  delay(5);
}

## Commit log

2025-12-02 test dataset
    [studyspace_data_dec2025_emoticon16.csv]
2025-12-10 code arduino update
2025-12-10 Add new assets and project settings for Digital Twin
    - Added CASA0019-1.fbx.meta file with model importer settings and animation configurations.
    - Created Script.meta file to define script folder asset properties.
    - Introduced SceneTemplateSettings.json to manage template pin states and dependency type information for various Unity asset types.
2025-12-10 Fix: displayer broken 5 pixels,
    [study_space.ino]
2025-12-10 添加旋转编码器控制器及其MQTT集成，支持物理旋转和按钮事件的同步
2025-12-10 添加TFT显示控制器，支持通过MQTT切换显示模式并显示房间信息
2025-12-10 修复：清理代码，移除多余空行
2025-12-10 添加：实现RoomInfoPanelController，集成MQTT消息处理与UI更新
2025-12-10 添加：实现房间模式切换的MQTT消息处理，支持即时更新房间数据
2026-01-04 wiring diagram
    [study space wiring.fzz]
2026-01-05 insert image reference
2026-01-06 insert video
